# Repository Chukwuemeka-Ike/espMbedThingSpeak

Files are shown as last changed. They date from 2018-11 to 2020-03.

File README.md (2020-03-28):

# HUD Alarm Clock
The code in this repo supports the HUD Alarm Clock project I developed using an mbed microcontroller.

## Background
This project arose from my interest in IOT. I wanted to start a basic project that integrated network connectivity with something relatively cool.

Every day, I have the same morning routine. Before I get out of bed, I check the time, then the weather - always in that order. I decided to combine these two tasks into one and have some fun in the process.

Thus the HUD alarm clock idea was born.

## Idea
The alarm clock gets its weather and time from two different websites which I linked through ThingSpeak APIs. The current temperature and time are then displayed on the semi-reflective screen.

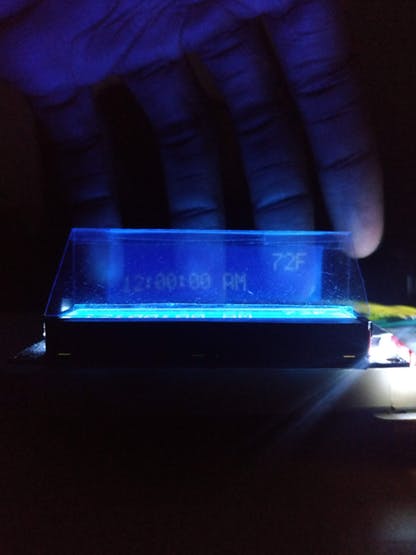
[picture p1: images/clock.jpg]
Dark room demonstration


In its current design, the HUD is several times better in low light settings. I am currently searching for a way to ensure the HUD is also visible in bright light.

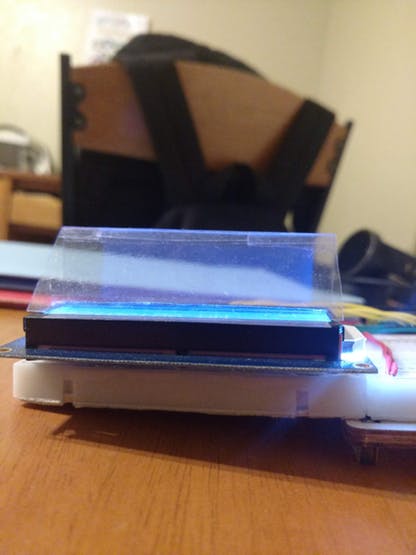
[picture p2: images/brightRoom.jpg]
Display not viewable in bright light


The system will connect to the internet via an ESP8266 wifi module. The alarm times will be set with code, while the alarm will sound from a small speaker.

The ESP8266 is not breadboard-friendly, so I had to solder jumpers onto the module.

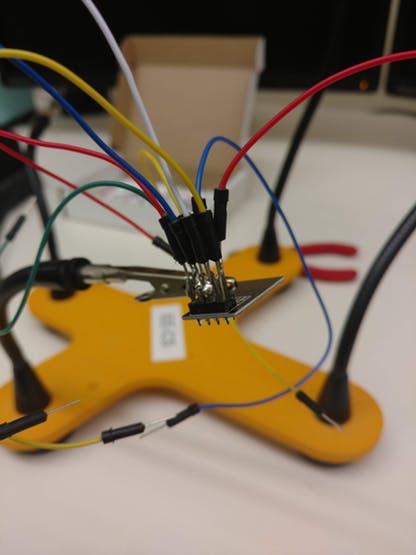
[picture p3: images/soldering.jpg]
Soldered ESP8266 module


The time and weather are accessed through a ThingSpeak API which can isolate parts of webpages and locate them on the ThingSpeak server for easy access. The process is outlined below:

## Weather and Time via ThingHTTP
In order to get the weather and time to the mBed, I used the ThingHTTP app from ThingSpeak to strip the desired information from a single web page.
1. To set up the simple web page that contains the time, a ThingHTTP app will need to be set up.
2. In ThingSpeak, go to the Apps toolbar and select ‘ThingHTTP.’
3. Select ‘New ThingHTTP, ’ give it an appropriate name - ‘LC Time’ in this example.
4. You will need to provide the URL of the target page: https://www.timeanddate.com/worldclock/usa/lake-charles.
5. Set Method to ‘GET, ’ and HTTP Version to 1.1. The last piece needed is the Parse String. To obtain this, navigate to the URL as above
6. The target component of the webpage is the time as displayed below:

Time

7. Right-click anywhere on the page and select ‘Inspect.’ This will provide an additional pane with the html code for the current web page. It takes some inspection to find the portion that displays the time on the page as highlighted below:

Inspect Element

8. Right-click this section of code and select ‘Copy XPath.’
9. Navigate back to the open ThingHTTP tab and paste this XPath into the Parse String field. This is all that is necessary to set up an API to access the time on the web page. Your ThingHTTP setup should bear some resemblance to the figure below

ThingHTTP Menu

10. Once this is saved, there should be a toolbar to the right of the page showing ‘GET https://api.thingspeak.com/apps/…’ You can confirm that the procedure up to this point has worked by copying this path and going to it in your browser. The response should be similar to below

Isolated Time

11. For the weather, the ThingHTTP process is the same. The only difference is that the data is sourced from slightly lower in the web page.

Weather

12. The target is the high and low for the day. Inspect the page to find the target area and copy the XPath.

Inspect Weather

13. Use a second ThingHTTP app with all the same parameters, but be sure to use the right Parse String for the weather. Check that this has been successful by navigating to the *https://api.thingspeak.com/apps/…* link that is generated. The result should be similar to that below:

Isolated Weather

  You have now set up the API’s for easy access to the necessary information.

## Testing
I included photos of the terminal output during the testing stage.
Server Response for Time Request

Server Response for the Time and Weather

## Challenges
1. The ESP-01 is not breadboard friendly, so jumper wires needed to be soldered on to provide proper connectivity.
2. The project was initially planned to be deployed on the Arduino Uno MCU with the ESP-01 providing WiFi capabilities. This presented a fairly simple issue - the Uno outputs 5V, but the ESP-01 runs on 3.3V. The proposed solution was to buy a bi-directional logic level converter (bi-di converter) to carry out the necessary logic level conversions between both boards.
3. Upon purchase and implementation of the converter, it was found that the converter had continuity issues. It is unclear whether this problem arose from my soldering, or if it was a defective board from the start.
4. The inability to use the bi-di converter made it unreliable to use the Arduino Uno in the project, and because I already had an mBed microcontroller which naturally outputs at 3.3V, I decided to switch the main board to the mBed NXP LPC1768.
5. Once a connection with the ThingSpeak server was made and the desired information could be reliably printed to the PC terminal, I attempted to connect the LCD and print out the data there. A new problem then reared its head - the connection with the server became unviable.
6. A ‘link error’ has been displayed on every connection attempt in the last 48 hours. I do not believe it is a result of the code or hardware as the same setup was used with success in the past. This is still being worked on at this time.

**Note**: It has since been discovered that the ESP can run on 5V from the Arduino as a professor at my university used the ESP in such a setup as of this time. It seems that connecting the Vcc pin to 5V instead of 3.3V might cause the ESP to take and output 5V logic levels. I have not tested this approach and neither encourage nor discourage it.

## Links/Credits
1. Simple tutorial by Jim Hamblen on wiring and code connecting the ESP8266 to the WLAN: https://os.mbed.com/users/4180_1/notebook/using-the-esp8266-with-the-mbed-lpc1768/
2. Information for connecting the GPIO pins: http://www.forward.com.au/pfod/ESP8266/GPIOpins/index.html
3. ESP8266 header files: https://os.mbed.com/teams/ESP8266/code/esp8266-driver/
4. Website used for time and date: https://www.timeanddate.com/worldclock/usa/lake-charles
5. Common AT commands for the ESP: https://github.com/espressif/ESP8266_AT/wiki
6. LCD Data Sheet: https://www.arduino.cc/documents/datasheets/LCDscreen.PDF

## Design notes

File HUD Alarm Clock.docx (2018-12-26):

Chukwuemeka Osaretin Ike

Mr. Brent Garner

ELEN 462-A

16 November 2018

HUD Alarm Clock

Background

This project came from the desire to develop an alarm clock with a heads-up display that could be viewed through a transparent film. It was intended to be a simple project utilizing parts that had fallen out of use in my home. The project stayed mostly true to that initial idea

The aim of this project was to develop my skills in implementing network protocols including HTTP for use in future IOT projects and applications. The project is a simple alarm clock that sources real-time weather and clock data from an online API provided by ThingSpeak, and it displays the information on an LCD screen which is reflected on a transparent secondary display.

At this time, the alarm clock is an unrefined prototype. The criteria stated in the Honors Option form have been met, but more work needs to be done to deliver a fully functional product. This document will also be updated and re-submitted accordingly.

Parts

1. mBed NXP LPC1768 MCU. This microcontroller was chosen because it was available from a previous class and the fact that it outputs 3.3V on its pins - the ESP’s preferred voltage level.
2. ESP8266 WiFi Module. This was the most complicated component in the whole setup and the main attraction. It is a $5 module that can add Wi-Fi capability to any project
3. JHD659 16x2 LCD Screen. This is our display. It is capable of holding 2 lines of 16 characters each. It runs on an SPI interface
4. Generic Piezoelectric Buzzer. This is the alarm for the intended alarm feature to be added at a later date
5. Generic button
6. 10 kΩ resistors. These were used in pulling the GPIO pins on the ESP up to 3.3V
7. Male-to-male headers

Hardware Connections

1. Upon shifting to the mBed, there was an initial inability to find a discernible tutorial on wiring the ESP-01 to the mBed. One was eventually found and the suggested wiring is listed below:
  a. Reset to p26
  b. TX to p27
  c. RX to p28
  d. GND and 3V3 to the corresponding pins
  e. CH_PD is the enable pin. Tie this HIGH.
  f. I believe GPIO0 and GPIO2 both need to be tied high through 10㏀ resistors, although this has not been confirmed. The board seems to react erratically at times to the position of the GPIO pins, but has been most accommodating of this setup. As of this writing, the ESP has been powered and used regularly for over two months without issue.

ESP Pin | Mbed Pin
RST | p26
TX | p27
RX | p28
GND | GND
3V3 | 3.3V
CH_PD or EN | 3.3V
GPIO0 | 3.3V through 10kΩ
GPIO2 | 3.3V through 10kΩ

Table 1: Mbed-ESP Wiring Table

2. Once reliable wiring was established, I wrote setup and configuration code based heavily on earlier work published by Jim Hamblen accessible at link 1 in the list of links further in this document.
3. The ESP-01 board works on AT (modem) commands. In the configuration code, these are copied into the module’s buffer in two stages. The first uses the “strcpy” and “strcat” C functions to change the contents of a pre-declared character array, and the second uses an esp.printf() function to copy these instructions into the buffer.
4. This method was employed because of an inability to find pre-written libraries for the ESP8266 module. The only library found presented more challenges than solutions, so I elected to abandon it.
5. The initial configuration code written by Jim Hamblen simply connects the ESP to the access point and acquires IP and MAC addresses for further use.

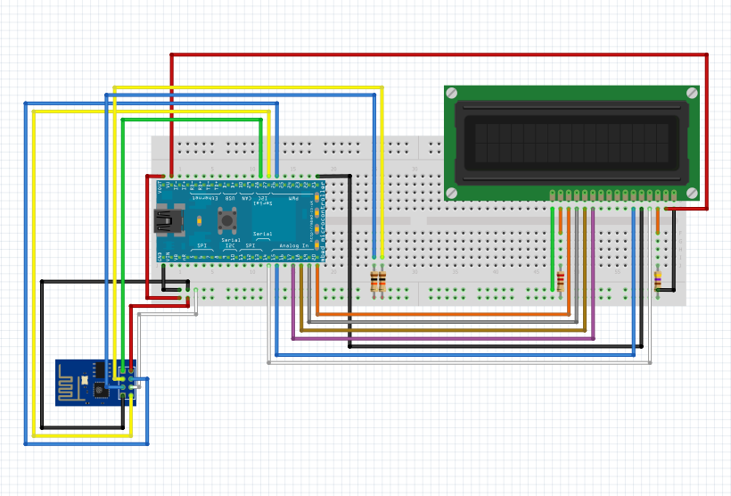
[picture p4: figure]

Figure 1: Wiring Schematic for the ESP module and LCD screen.

Weather and Time via ThingHTTP

1. In order to get the weather and time to the mBed, I used the ThingHTTP app from ThingSpeak to strip the desired information from a single web page.
2. To set up the simple web page that contains the time, a ThingHTTP app will need to be set up.
3. In ThingSpeak, go to the Apps toolbar and select ‘ThingHTTP.’
4. Select ‘New ThingHTTP,’ give it an appropriate name - ‘LC Time’ in this example
5. You will need to provide the URL of the target page: https://www.timeanddate.com/worldclock/usa/lake-charles.
6. Set Method to ‘GET,’ and HTTP Version to 1.1. The last piece needed is the Parse String. To obtain this, navigate to the URL as above
7. The target component of the webpage is the time as displayed below:

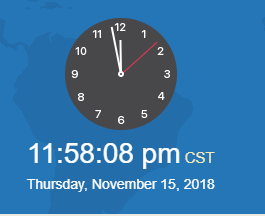
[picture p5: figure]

8. Right-click anywhere on the page and select ‘Inspect.’ This will provide an additional pane with the html code for the current web page. It takes some inspection to find the portion that displays the time on the page as highlighted below:

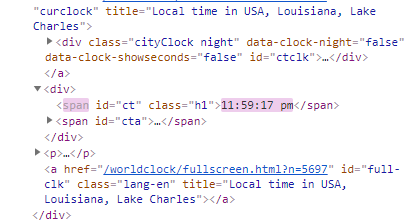
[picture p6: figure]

9. Right-click this section of code and select ‘Copy XPath.’
10. Navigate back to the open ThingHTTP tab and paste this XPath into the Parse String field. This is all that is necessary to set up an API to access the time on the web page. Your ThingHTTP setup should bear some resemblance to the figure below

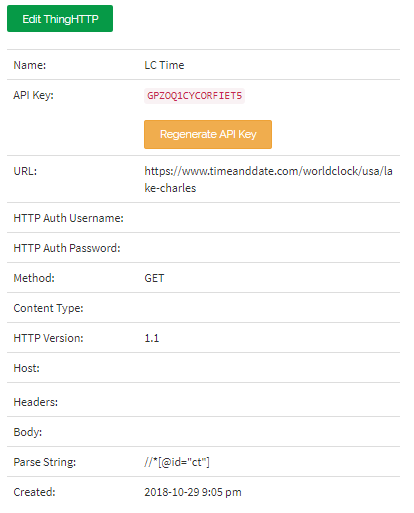
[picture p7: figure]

11. Once this is saved, there should be a toolbar to the right of the page showing ‘GET https://api.thingspeak.com/apps/… (https://api.thingspeak.com/apps/%E2%80%A6)’ You can confirm that the procedure up to this point has worked by copying this path and going to it in your browser. The response should be similar to below

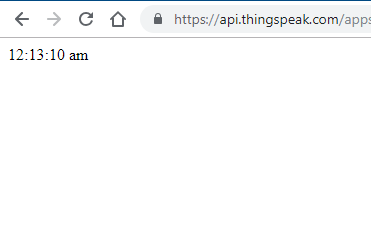
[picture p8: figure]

12. For the weather, the ThingHTTP process is the same. The only difference is that the data is sourced from slightly lower in the web page.
13. The target is the high and low for the day. Inspect the page to find the target area and copy the XPath.

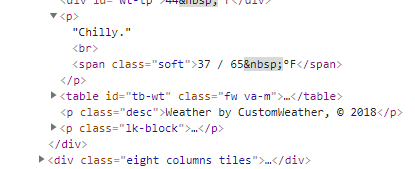
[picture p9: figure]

14. Use a second ThingHTTP app with all the same parameters, but be sure to use the right Parse String for the weather. Check that this has been successful by navigating to the https://api.thingspeak.com/apps/… (https://api.thingspeak.com/apps/%E2%80%A6) link that is generated. The result should be similar to that below:

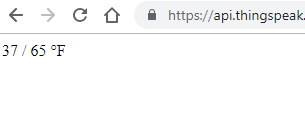
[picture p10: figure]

15. You have now set up the API’s for easy access to the necessary information.

Code

The C++ code is accessible in the main.cpp file at:

https://github.com/Chukwuemeka23/espMbedThingSpeak/blob/master/main.cpp

This code will be updated to be more effective and scalable once this semester is over.

Testing

The terminal output showing the server’s response to the time request:

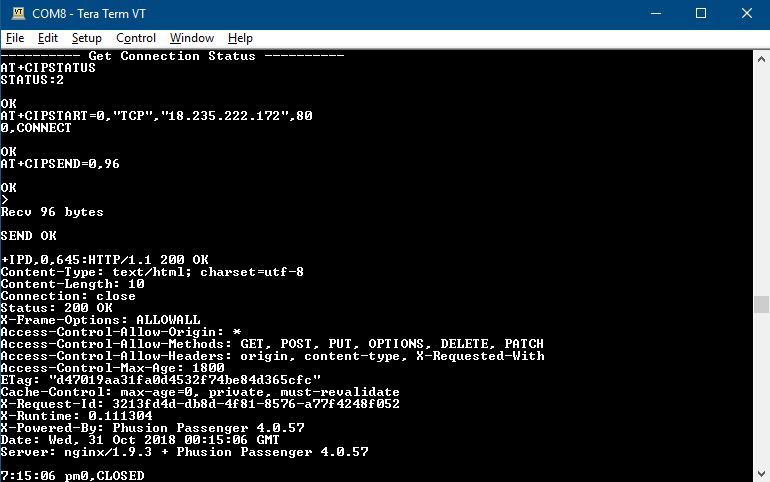
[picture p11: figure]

Terminal output after parsing the server’s response for just the time and weather in each case:

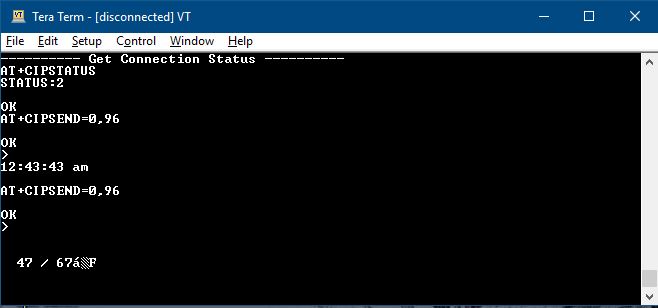
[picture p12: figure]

Challenges

1. The ESP-01 is not breadboard friendly, so jumper wires needed to be soldered on to provide proper connectivity.
2. The project was initially planned to be deployed on the Arduino Uno MCU with the ESP-01 providing WiFi capabilities. This presented a fairly simple issue - the Uno outputs 5V, but the ESP-01 runs on 3.3V. The proposed solution was to buy a bi-directional logic level converter (bi-di converter) to carry out the necessary logic level conversions between both boards.
3. Upon purchase and implementation of the converter, it was found that the converter had continuity issues. It is unclear whether this problem arose from my soldering, or if it was a defective board from the start.
4. The inability to use the bi-di converter made it unreliable to use the Arduino Uno in the project, and because I already had an mBed microcontroller which naturally outputs at 3.3V, I decided to switch the main board to the mBed NXP LPC1768.
5. Once a connection with the ThingSpeak server was made and the desired information could be reliably printed to the PC terminal, I attempted to connect the LCD and print out the data there. A new problem then reared its head - the connection with the server became unviable.
6. A ‘link error’ has been displayed on every connection attempt in the last 48 hours. I do not believe it is a result of the code or hardware as the same setup was used with success in the past. This is still being worked on at this time.

Note: It has since been discovered that the ESP can run on 5V from the Arduino as Mr. Mitch

Morgan is using the ESP in such a setup as of this time. It seems that connecting the Vcc pin to 5V instead of 3.3V might cause the ESP to take and output 5V logic levels. I have not tested this approach and neither encourage nor discourage it.

Links

1. Simple tutorial by Jim Hamblen on wiring and code connecting the ESP8266 to the WLAN: https://os.mbed.com/users/4180_1/notebook/using-the-esp8266-with-the-mbed-lpc1768/
2. Information for connecting the GPIO pins: http://www.forward.com.au/pfod/ESP8266/GPIOpins/index.html
3. ESP8266 header files: https://os.mbed.com/teams/ESP8266/code/esp8266-driver/
4. Website used for time and date: https://www.timeanddate.com/worldclock/usa/lake-charles
5. Common AT commands for the ESP: https://github.com/espressif/ESP8266_AT/wiki
6. LCD Data Sheet: https://www.arduino.cc/documents/datasheets/LCDscreen.PDF

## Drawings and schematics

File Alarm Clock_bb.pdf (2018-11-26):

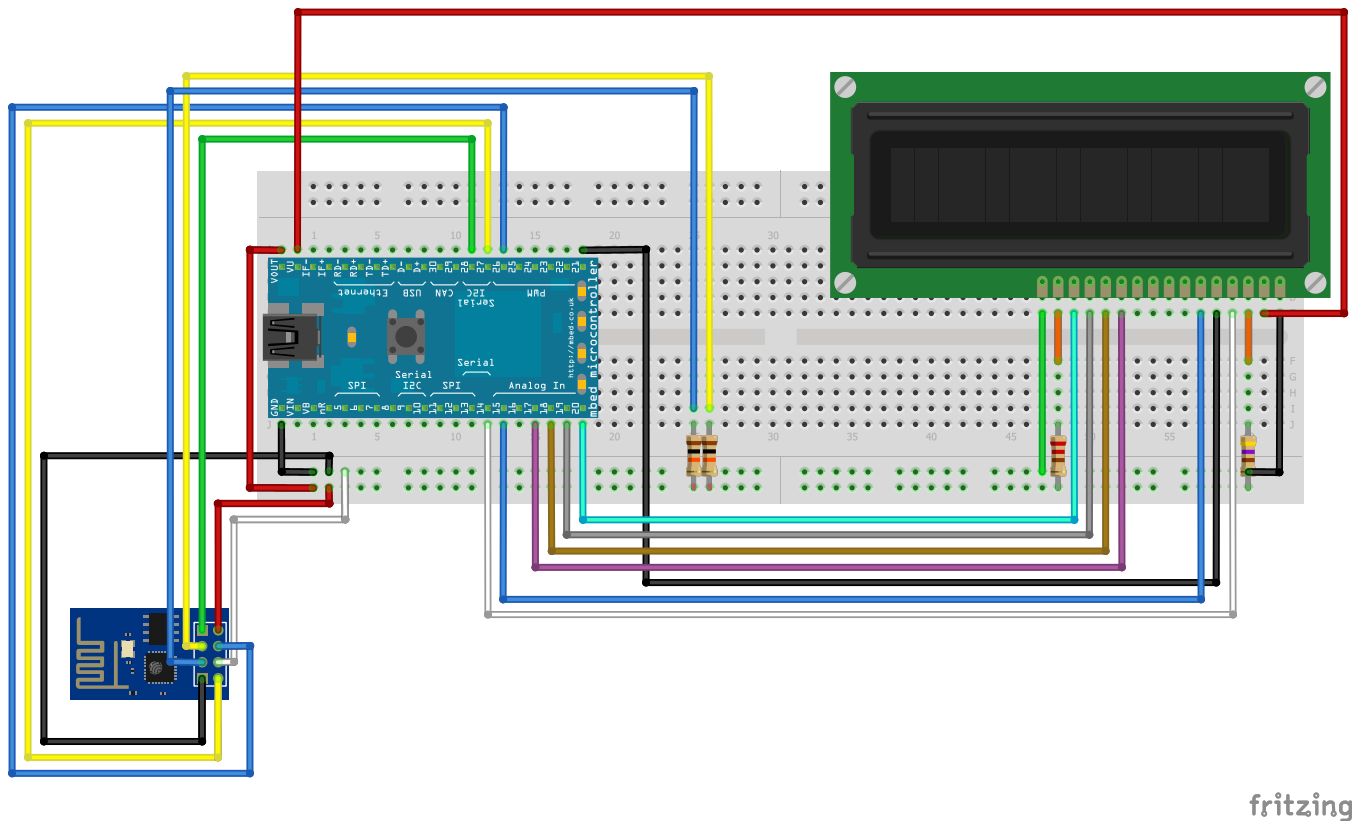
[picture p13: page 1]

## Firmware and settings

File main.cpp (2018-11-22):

/*
*   Program: Alarm Clock and Local Weather Display
*   Author: Chukwuemeka Osaretin Ike
*   Description: This program uses an ESP8266 and mBed board in collecting and displaying the local time and weather
*                for Lake Charles, LA. It can be modified, albeit with a few involved steps, to work for any location.
*   Credit: Jim Hamblen - The setup for the ESP8266 was heavily based on his original code at:
*           https://os.mbed.com/users/4180_1/notebook/using-the-esp8266-with-the-mbed-lpc1768/
*
*
*
*
*/

#include "mbed.h"
#include "TextLCD.h"

TextLCD lcd(p14, p21, p15, p17, p18, p19, p20, TextLCD::LCD16x2);   // Initialize the LCD object

// Set the universal baud rate for all serial connections (ESP & PC)
#define baudRate 115200

DigitalOut myled(LED1);         // Declare the LED as an indicator of proper operation. Put more LEDs to indicate different things.
Serial pc(USBTX, USBRX);        // PC Serial terminal
Serial esp(p28, p27);           // ESP TX and RX pins
DigitalOut reset(p26);          // ESP RST pin
Timer t;

// ----------------------------------- Enter Access Point Credentials Here -------------------------------------------------
char ssid[32] = "YOURWIFI";       // enter WiFi router ssid inside the quotes
char pwd [32] = "YOURPASSWORD";     // enter WiFi router password inside the quotes

// The HTTP requests for the time and weather from ThingSpeak. Note: The API keys should be your own unique keys.
char timeAPI[] =    "GET /apps/thinghttp/send_request?api_key=GPZOQ1CYCORFIET5 HTTP/1.1\r\nHost: api.thingspeak.com\r\n"; 
char weatherAPI[] = "GET /apps/thinghttp/send_request?api_key=IRXOT0ZPTZLRPFT0 HTTP/1.1\r\nHost: api.thingspeak.com\r\n";
char closeConnection[] = "Connection: close\r\n\r\n";
char httpPort[] = "8080";                  // Set HTTP port

// ThingSpeak IP Address. Confirmed this with an ICMP ping request
char thingSpeakIP[] = "18.235.222.172";

// Variables necessary for comms with the ESP.
int  count;
int ended;
int timeout;

// Containers for commands and comms responses (Server and ESP)
char buffer[1024];
char payload[1024];
char currentTime[13];
char currentWeather[13];
char snd[255];

// Declare the necessary functions for working with the ESP
void sendCMD();
void getReply();
void ESPconfig();
void ESPSetBaudRate(int);

// Functions for acquiring the current weather and time
void getTime(void);
void getWeather(void);
void thingSpeakConnect(void);


int main()
{
    reset = 0;                  // Hardware reset the ESP8266

    lcd.cls();
    pc.baud(baudRate);          // Set up pc terminal with appropriate baud rate
    lcd.printf("Hello.");
    pc.printf("\f\n\r-------------ESP8266 Hardware Reset-------------\n\n\r");
    wait(0.5);
    reset = 1;
    timeout = 2;
    getReply();

    esp.baud(baudRate);         // Set up ESP serial communication
    // ESPSetBaudRate(baudRate);   // Set the ESP's baud rate

    // Configure the ESP8266
    ESPconfig();


    thingSpeakConnect();        // Use the AT+CIPSTART command to connect to the thingspeak ip address
    getTime();                  // Send the HTTP request for time to ThingSpeak's server
    getWeather();               // Send HTTP request for the weather to ThingSpeak's server

}


// ---------------------------------------------- Sets the ESP8266 baud rate -------------------------------------------------
// This function has not been implemented at this time.
void ESPSetBaudRate(int a)
{
    char* bRate;
    sprintf(bRate, "%d", a);
    strcpy(snd, "AT+CIOBAUD=");
    strcat(snd, bRate);
    strcat(snd, "\r\n");
    sendCMD();
}


//  ------------------------- This is for ESP8266 config only, run this once to set up the ESP8266 ---------------------------
void ESPconfig()
{

    // Send 'AT' to the ESP twice to confirm that serial communication has been established
    wait(0.5);
    strcpy(snd,"AT\r\n");
    sendCMD();
    wait(0.5);
    strcpy(snd,"AT\r\n");
    sendCMD();
    timeout=1;
    getReply();
    wait(1);
    pc.printf("\f---------- Starting ESP Config ----------\r\n\n");

    pc.printf("---------- Reset & Get Firmware ----------\r\n");
    strcpy(snd,"AT+RST\r\n");
    sendCMD();
    timeout = 1;
    getReply();
    pc.printf(buffer);

    wait(1.5);

    pc.printf("\n---------- Get Version ----------\r\n");
    strcpy(snd,"AT+GMR\r\n");
    sendCMD();
    timeout = 2;
    getReply();
    pc.printf(buffer);

    wait(1.5);

    // Set CWMODE to 1 for Station, 2 for Access Point, 3 for BOTH. This method needs only the station mode.
    pc.printf("\n---------- Setting Mode ----------\r\n");
    strcpy(snd, "AT+CWMODE=1\r\n");
    sendCMD();
    timeout = 1;
    getReply();
    pc.printf(buffer);

    wait(1.5);

    // Set CIPMUX to 0 for Single connection mode, 1 for Multiple connections. 1 is beneficial for this project, but not necessary.
    pc.printf("\n---------- Setting Connection Mode ----------\r\n");
    strcpy(snd, "AT+CIPMUX=1\r\n");
    sendCMD();
    timeout = 1;
    getReply();
    pc.printf(buffer);

    wait(1.5);

    pc.printf("------- Connecting --------\n\rssid = %s \n\rpwd = %s\r\n", ssid, pwd);
    lcd.cls();
    lcd.printf("Connecting...");

    // Send the ESP the credentials of the WLAN to connect to.
    strcpy(snd, "AT+CWJAP=\"");
    strcat(snd, ssid);
    strcat(snd, "\",\"");
    strcat(snd, pwd);
    strcat(snd, "\"\r\n");
    sendCMD();
    timeout = 3;
    getReply();
    pc.printf(buffer);

    wait(3);

    pc.printf("\n---------- Get IP & MAC Addresses ----------\r\n");
    strcpy(snd, "AT+CIFSR\r\n");
    sendCMD();
    timeout = 5;
    getReply();
    pc.printf(buffer);

    wait(1.5);

    pc.printf("\n---------- Get Connection Status ----------\r\n");
    strcpy(snd, "AT+CIPSTATUS\r\n");
    sendCMD();
    timeout = 3;
    getReply();
    pc.printf(buffer);

}

// ------------------------- sendCMD serially prints the current command in the snd array to the esp. ----------------------
void sendCMD()
{
    esp.printf("%s", snd);
}

// ------------------ This function gets the contents of the ESP's memory and places them in the buffer array --------------
void getReply(void)
{
    memset(buffer, '\0', sizeof(buffer));
    t.start();
    ended = 0;
    count = 0;
    while(!ended) {
        if(esp.readable()) {
            buffer[count] = esp.getc();
            count++;
        }
        if(t.read() > timeout) {
            ended = 1;
            t.stop();
            t.reset();
        }
    }
}

// ---------------------------------- Set up IP connection with ThingSpeak's server --------------------------------------
void thingSpeakConnect(void)
{
    strcpy(snd,"AT+CIPSTART=0,\"TCP\",\"");
    strcat(snd,thingSpeakIP);
    strcat(snd,"\",");
    strcat(snd, httpPort);
    strcat(snd, "\r\n");
    sendCMD();
    timeout = 10;
    getReply();
    pc.printf(buffer);
    timeout = 5;
    getReply();
    pc.printf(buffer);
}

// ---------------------- Get the current time ------------------------------
void getTime(void)
{
    strcpy(snd, "AT+CIPSEND=0,96\r\n");
    sendCMD();
    timeout = 5;            // was 5
    getReply();
    pc.printf(buffer);
    strcpy(snd, timeAPI);
    strcat(snd, "\r\n");
    sendCMD();
    timeout = 5;            // was 5
    getReply();
    pc.printf(buffer);
    pc.printf("\n\n\n");

    for(int i = 0; i < 1024; i++) {
        payload[i] = buffer[i];
    }

    for(int i = 0; i < 13; i++) {
        currentTime[i] = payload[674+i];
        pc.printf("%c", currentTime[i]);
        lcd.printf("%c", currentTime[i]);
    }
    pc.printf("\n\n\r");

}

// ------------------------- Get the weather -----------------------------
void getWeather(void)
{
    strcpy(snd, "AT+CIPSEND=0,96\r\n");
    sendCMD();
    timeout = 5;            // was 5
    getReply();
    pc.printf(buffer);
    strcpy(snd, weatherAPI);
    strcat(snd, "\r\n");
    sendCMD();
    timeout = 5;            // was 5
    getReply();
    pc.printf(buffer);
    pc.printf("\n\n\n");

    for(int i = 0; i < 1024; i++) {
        payload[i] = buffer[i];
    }

    lcd.locate(1,0);

    for(int i = 0; i < 12; i++) {
        currentWeather[i] = payload[695+i];
        pc.printf("%c", currentWeather[i]);
        lcd.printf("%c", currentWeather[i]);
    }
    pc.printf("\n\n\r");
}
